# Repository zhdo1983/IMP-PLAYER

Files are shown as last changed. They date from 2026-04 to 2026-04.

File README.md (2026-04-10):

https://github.com/user-attachments/assets/7eb9eef1-41f4-46a2-858e-66c2568c89ac

mmexport1775849875180

IMP-PLAYER: The ESP32-WROOM Network Audio Terminal
1. Project Overview
IMP-PLAYER is a high-performance audio terminal based on the ESP32-WROOM-32 (No-PSRAM version). It is designed to push the hardware's physical limits, integrating network streaming, local playback, and complex UI interactions within a highly constrained memory environment.
mmexport1775849868553

🚀 Core Features
Network Streaming: High-stability streaming (MP3/AAC) with HTTPS support.

Navidrome Integration: Full Subsonic/Navidrome API support for personal cloud music.

SD Card Player: Local MP3 playback with dynamic folder scanning.

Advanced UI/UX: 128x64 OLED display with real-time spectrum analysis and smooth animations.

System Utilities: NTP network clock, battery monitoring, and a built-in PONG game.

Maintenance: Web-based WiFi configuration portal and OTA (Over-the-Air) firmware updates.

mmexport1775849851039

This project is specifically optimized for the Non-PSRAM ESP32-WROOM chip:

Dynamic Memory Orchestration: Implements a "模式切换即清场" (Clear-on-Switch) strategy. Metadata and buffers are dynamically allocated and freed to ensure 80KB+ contiguous heap for HTTPS handshakes.

Anti-Fragmentation Hack: Uses a "Silent Handshake" technique (connecting to 127.0.0.1) to force the network stack to flush buffers and defragment the heap before critical operations.

Multitasking: Decoupled FreeRTOS tasks for OLED rendering, audio decoding, and system monitoring.
2. Hardware
Component   Specification
MCU     	 ESP32-WROOM-32 (4MB Flash, No PSRAM)
Audio      DAC/Amp	MAX98357A I2S Class-D Amplifier
Display   	SSD1306 128x64 OLED (I2C)
Storage	   TF/MicroSD Card (SPI Mode)
Input	     EC11 Rotary Encoder
Lithium battery (3.7V) 602535P 600mAh x1
2.1 Pin Mapping
ESP32     Pin	     Component	Description
GPIO5	    SD_CS	SD    Card Chip Select
GPIO18   	SPI_SCK	    SD Card Clock
GPIO19	  SPI_MISO  	SD Card MISO
GPIO23	  SPI_MOSI	  SD Card MOSI
GPIO4   	OLED_SDA	  OLED I2C Data
GPIO14	  OLED_SCL	  OLED I2C Clock
GPIO25	  I2S_LRCK	  I2S Left/Right Clock
GPIO26	  I2S_BCLK	  I2S Bit Clock
GPIO22	  I2S_DOUT	  I2S Data Out
GPIO32	  ENC_A	      Encoder Phase A
GPIO33	  ENC_B	      Encoder Phase B
GPIO35	  ENC_SW	    Encoder Button
GPIO34	  BAT_ADC	    Battery Voltage Detection

3. Installation & Compilation
Prerequisites
Framework:  PlatformIO.

Required Libraries
Please install the following libraries via the Library Manager:

ESP32-audioI2S (by schreibfaul1)

U8g2 (by olikraus)

ArduinoJson

NTPClient

Configuration
Open config.h.

(Optional) Set your default WiFi credentials or use the Web Portal later.

Configure your Navidrome server address and API credentials.

### 🔨 Building with PlatformIO
This project uses **PlatformIO** for advanced memory and library management.

1. Clone the repository.
2. Open the folder in VS Code with the PlatformIO extension installed.
3. The `platformio.ini` will automatically handle dependencies (Audio, U8g2, ArduinoJson, etc.).
4. Click **Upload** to flash the ESP32-WROOM.

## 🔌 Hardware & PCB Design

The project includes complete hardware design files, allowing you to build your own IMP-PLAYER.

### Files Location:
### Files Location:
- **Schematic:** [/Hardware/PCB_PCB1_2026-04-11.pdf](./Hardware/PCB_PCB1_2026-04-11.pdf)  - Check here for pin definitions and circuit logic.
- **EasyEDA Project:** [/Hardware/ProDoc_PCB1_2026-04-11.EPRO2](./Hardware/ProDoc_PCB1_2026-04-11.EPRO2)
- You can import this directly into [LCEDA (EasyEDA)](https://pro.lceda.cn/) for modification.

### Key Hardware Features:
- **ESP32-WROOM-32** Core (Fully utilizing the internal SRAM).
- **MAX98357A** I2S DAC for high-quality audio output.
- **Battery Management:** Integrated charging circuit with ADC voltage monitoring.
- **Form Factor:** Optimized to fit the custom 3D-printed case.

### Manufacturing:
You can export the **Gerber files** from the `.EPRO2` file using EasyEDA and send them to manufacturers like JLCPCB for production.

3.1 Initial Configuration (Code Level)
Before flashing, you must set your default server endpoints in the source code:
----------------------------------------------------------------------------------------------------------
OTA Configuration: Locate lines 96-97 in config.h:
  #define OTA_DEFAULT_VER_URL  "http://your-server/version.txt"
  #define OTA_DEFAULT_FW_URL   "http://your-server/firmware.bin"
  Navidrome Default: Locate line 41 in navidrome.h:  
   #define ND_DEFAULT_SERVER "https://your-navidrome-url"

----------------------------------------------------------------------------------------------------------

5. Web Interface
The device hosts a local web server for advanced configuration:

Network: Scan and manage WiFi saved slots.

Navidrome: Configure server URL and User Token.

OTA: Upload new .bin firmware files wirelessly.

5.1 Backend Server Requirements
Navidrome Setup
Create a standard user account in your Navidrome instance.

You do not need to hardcode the password. Open the filebrowser Web Portal (after connecting to the device's WiFi) to enter the Username and Password. The device will automatically generate the MD5 Token for secure API communication.

OTA File Server
To use the OTA update feature, you need a simple HTTP file server (like Nginx, Apache, or a simple Python file server) hosting two files:

firmware.bin: The compiled binary of the project.

version.txt: A plain text file containing only the version number (e.g., 1.0.2).
The device compares the string in version.txt with its internal version to trigger an update.

6. Disclaimer & Contribution
⚠️ Disclaimer
This project is an experimental implementation of high-concurrency tasks on low-resource hardware. While it includes several memory-safety hacks (like the 127.0.0.1 handshake), unexpected reboots may occur under extreme network jitter or with overly large SD card directories (recommended < 500 tracks).

🤝 Contributing
This project was developed with the assistance of AI to optimize low-level memory management. If you find bugs or have ideas for even tighter memory optimization, please feel free to open an Issue or submit a Pull Request.

7. License
This project is licensed under the MIT License.

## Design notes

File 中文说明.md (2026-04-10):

# IMP-PLAYER
This is a player with functions including MP3 playback, network streaming media playback, Navidrome playback, music clock, and web service.
# ESP32-MAX98357 网络收音机使用说明书

## 一、项目概述

这是一个ESP32网络收音机和SD卡MP3播放器项目，采用模块化设计，主要特性包括：

**核心功能：**
- ✅ 网络电台流媒体播放（支持MP3/AAC格式）
- ✅ SD卡本地MP3文件播放
- ✅ 128x64 OLED显示屏（中文支持）
- ✅ 旋转编码器控制
- ✅ WiFi配置Portal
- ✅ OTA固件升级
- ✅ 电池电量监测
- ✅ PONG游戏
- ✅ NTP网络时钟同步

**硬件配置：**
- 主控：ESP32-WROOM-32
- 功放：MAX98357A I2S D类放大器
- 显示：SSD1306 128x64 OLED
- 存储：TF卡（SPI接口）
- 输入：EC11旋转编码器

## 二、硬件连接说明

### 2.1 引脚定义

| ESP32引脚 | 连接模块 | 说明 |
|---|---|---|
| GPIO5 | SD_CS | SD卡片选 |
| GPIO18 | SPI_SCK | SD卡时钟 |
| GPIO19 | SPI_MISO | SD卡数据输入 |
| GPIO23 | SPI_MOSI | SD卡数据输出 |
| GPIO4 | OLED_SDA | OLED I2C数据 |
| GPIO14 | OLED_SCL | OLED I2C时钟 |
| GPIO25 | I2S_DOUT | I2S音频输出 |
| GPIO26 | I2S_LRC | I2S左右声道时钟 |
| GPIO27 | I2S_BCLK | I2S位时钟 |
| GPIO21 | I2S_SD_MODE | MAX98357A使能 |
| GPIO32 | ENCODER_CLK | 编码器时钟 |
| GPIO16 | ENCODER_DT | 编码器数据 |
| GPIO17 | ENCODER_SW | 编码器按钮 |
| GPIO36 | BAT_DAC | 电池检测 |
| GPIO33 | LED_BLUE | 状态LED |

### 2.2 硬件清单

- ESP32-WROOM-32E *1
- MAX98357A I2S x2
- SSD1306 128x64 OLED显示屏 x1
- SD卡模块（SPI接口）x1
- TF卡 x1
- EC11旋转编码器 x1
- 锂电池（3.7V）602535P 600mah x1
- 充电管理模块 x1
- 扬声器（4Ω 3W）x2
- 若干电阻电容和杜邦线

-----------------------------------------------------------------------

OTA服务器和navidrome服务器录入方式：

 configh,h    96-97行 

#define OTA_DEFAULT_VER_URL  ""  // 默认版本检查URL
#define OTA_DEFAULT_FW_URL   ""  // 默认固件下载URL

navidrome.h 41行

ND_DEFAULT_SERVER "https://"  // 默认Navidrome服务器地址

---------------------------------------------------------------------------------------------------------------------
服务器端navidrome 建立用户， 在imp播放器WEB页面录入用户名密码
OTA服务器 使用impplayer文件服务器， 需要2个文件，一个firmware.bin， 一个version.txt
----------------------------------------------------------------------------------------------------------------------
喇叭使用 2030腔体喇叭

代码由于内存空间太小，使用中可能存在一些问题，若有发现，请分享给我
----------------------------------------------------------------------------------------------------------------------
项目中使用了很多其他网友的电路设计及代码设计， 在此感谢

=====================================================================================================================
## 三、首次使用指南

### 3.1 烧录固件

#### 使用PlatformIO编译和上传

### 3.2 WiFi配置

首次上电后设备会自动进入配网模式：

1. **连接WiFi热点**
   - 在手机或电脑WiFi列表中找到 `ESP32_Radio`
   - 连接该热点（无密码）

2. **打开配置页面**
   - 在浏览器中访问：`http://192.168.3.3`
   - 会看到配置界面

3. **输入WiFi信息**
   - 输入你的WiFi名称（SSID）
   - 输入WiFi密码
   - 点击"添加WiFi"按钮
   - 可以添加最多5个WiFi账号

4. **保存并重启**
   - 点击底部的"保存并重启"按钮
   - 设备会自动重启并连接WiFi

### 3.3 测试播放

重启后设备会自动：
- 连接WiFi
- 播放默认电台（默认为第8个电台：Radio Paradise）

**基本操作：**
- 旋转编码器：调节音量（0-21级）
- 按下编码器按钮：进入主菜单

## 四、功能使用说明

### 4.1 主菜单操作

按下编码器按钮进入主菜单，包含以下功能：

1. **选择电台** - 选择网络电台播放
2. **SD卡播放器** - 播放SD卡MP3文件
3. **时钟显示** - 显示NTP网络时间
4. **PONG游戏** - 弹球游戏
5. **WiFi设置** - 重新配置WiFi
6. **恢复出厂设置** - 恢复默认电台列表
7. **内存分配** - 查看内存使用情况

**菜单操作：**
- 旋转编码器：上下移动选择项
- 按下按钮：确认选择
- 10秒无操作自动返回

### 4.2 网络电台播放

**选择电台：**
1. 在主菜单选择"1.选择电台"
2. 旋转选择电台
3. 按下确认播放

**电台管理：**
- 通过Web界面管理电台
- 访问设备IP地址
- 可以添加、编辑、删除电台
- 最多保存20个电台

**默认电台列表：**
1. 德意志广播电台 WDR Einslive
2. 经典欧美 181.FM - Awesome 80's
3. 法国广播电台
4. 俄罗斯 PADNO
5. 德国 Hit-Radio FFH
6. 马来西亚 RTM Radio
7. 新加坡 88.3jia
8. 天堂电台 Radio Paradise
9. 芝加哥 WZRD The Wizard 88.3 FM
10. 苏腊巴亚 smart FM88.9
11. AFN Daegu - Korea
12. Swiss Jazz (瑞士爵士乐)

### 4.3 SD卡播放器

**准备工作：**
1. 将TF卡格式化为FAT32
2. 将MP3文件复制到卡中（支持子目录）
3. 将TF卡插入SD卡模块

**使用SD卡播放器：**
1. 在主菜单选择"2.SD卡播放器"
2. 首次使用会自动扫描SD卡
3. 扫描完成后自动开始播放

**播放控制：**
- 进入SD播放器控制菜单
- 旋转选择控制选项
  1. 下一首
  2. 上一首
  3. 播放/暂停
  4. 播放模式
  5. PONG游戏
  6. 切换效果图
  7. 退出

**播放模式：**
1. 单曲循环 - 当前曲目循环播放
2. 顺序播放 - 按列表顺序播放
3. 随机播放 - 随机选择曲目

**播放动画：**
- 12种播放动画可选
- 在"切换效果图"菜单中设置
- 动画效果包括：九宫格、圆环、五分割圆环、三角形切换、旋转圆弧、音频指示器、正弦频谱、爱心跳动、方块滚动、日月旋转、斜线下雨、气泡上升

**退出SD播放：**
- 选择"7.退出"选项
- 设备会自动释放资源并重启

### 4.4 时钟显示

1. 在主菜单选择"3.时钟显示"
2. 设备会自动从NTP服务器同步时间
3. 显示当前网络时间
4. 按下按钮返回主菜单

### 4.5 PONG游戏

1. 在主菜单选择"4.PONG游戏"
2. 游戏规则：
   - 控制左侧挡板
   - 击球到对方得一分
   - 先得5分获胜
3. 操作：
   - 旋转编码器控制挡板上下移动
   - 按下按钮返回主菜单

### 4.6 WiFi设置

**重新配置WiFi：**
1. 在主菜单选择"5.WiFi设置"
2. 设备会进入配网模式
3. 按照首次使用配置WiFi的步骤操作

**WiFi多账号管理：**
- 最多保存5个WiFi账号
- 设备启动时自动选择信号最强的连接
- 可以通过Web界面添加或删除WiFi

### 4.7 恢复出厂设置

1. 在主菜单选择"6.恢复出厂设置"
2. 设备会恢复默认电台列表
3. 恢复默认设置
4. 自动重启

### 4.8 内存分配查看

1. 在主菜单选择"7.内存分配"
2. 显示当前内存使用情况
3. 信息包括：
   - 总内存
   - 空闲内存
   - WiFi占用
   - SSL占用
   - 音频占用

### 4.9 OTA固件升级

**检查更新：**
1. 在主菜单→播放器选择→选择"OTA"选项
2. 设备会自动检查服务器版本
3. 如果有新版本，会提示升级

**执行升级：**
1. 选择"1.升级"开始升级
2. 升级过程中不要断电
3. 升级完成后自动重启

## 五、串口命令

通过串口终端可以输入以下命令：

### 5.1 可用命令

```
help          - 显示帮助信息
refresh       - 刷新SD卡数据库
refreshsd     - 刷新SD卡数据库（同上）
dbinfo        - 显示数据库信息
<URL>         - 直接播放网络流（输入URL）

## 六、Web管理界面

### 6.1 访问Web界面

1. 确保设备已连接WiFi
2. 在串口输出中查看设备IP地址
3. 在浏览器中访问该IP地址

### 6.2 电台管理

**查看电台列表：**
- 页面显示所有已保存的电台
- 显示电台名称和URL

**添加电台：**
1. 在"添加新电台"区域输入电台名称
2. 输入电台URL
3. 点击"添加电台"按钮

**编辑电台：**
1. 直接在列表中修改电台名称和URL
2. 点击"保存"按钮

**删除电台：**
1. 点击电台右侧的"删除"按钮
2. 确认删除

### 6.3 WiFi管理

**查看WiFi列表：**
- 显示所有已保存的WiFi账号
- 显示SSID（不显示密码）

**添加WiFi：**
1. 在"新增 WiFi 名称"输入SSID
2. 在"密码"输入WiFi密码（无密码留空）
3. 点击"添加 WiFi"按钮

**删除WiFi：**
1. 点击WiFi右侧的"删除"按钮
2. 确认删除

## 七、常见问题解答

### 7.1 连接问题

**Q: WiFi连接失败？**
A:
- 检查WiFi密码是否正确
- 尝试重启设备
- 检查WiFi信号强度
- 尝试删除后重新添加WiFi账号

**Q: SD卡无法识别？**
A:
- 确保SD卡格式化为FAT32
- 使用Class 10或更高速的SD卡
- 检查SD卡是否损坏
- 重新插拔SD卡

**Q: 播放无声音？**
A:
- 检查I2S接线是否正确
- 确保MAX98357A供电正常（3.3V-5V）
- 检查扬声器连接
- 确认音量已调节

### 7.2 播放问题

**Q: 电台播放卡顿？**
A:
- 检查网络连接质量
- 尝试更换其他电台
- 检查WiFi信号强度
- 重启设备

**Q: SD播放失败？**
A:
- 确认MP3文件格式正确
- 检查文件是否损坏
- 确认SD卡容量未满
- 重新扫描SD卡

**Q: 频繁自动重启？**
A:
- 可能是内存不足
- 减少SD卡MP3数量
- 优化播放列表
- 检查是否超过最大曲目数（500首）

### 7.3 内存问题

**Q: 如何查看内存使用？**
A:
- 进入主菜单→内存分配
- 查看详细的内存信息
- 监控内存变化

**Q: 内存不足怎么办？**
A:
- 减少SD卡MP3数量
- 优化电台列表
- 避免频繁切换电台
- 重启设备释放内存

### 7.4 其他问题

**Q: 电池电量显示不准？**
A:
- 电池检测基于ADC值，需要校准
- 根据实际电池特性调整参数
- 查看电池.h文件中的ADC阈值

**Q: 如何更新固件？**
A:
- 通过OTA升级（见4.9节）
- 或通过USB重新烧录固件

**Q: 串口波特率是多少？**
A: 115200

## 八、技术规格

### 8.1 硬件参数

| 参数 | 数值 |
|------|------|
| 工作电压 | 3.3V / 5V (USB供电) |
| 锂电池电压 | 3.7V |
| 音频输出 | 3W @ 4Ω |
| 显示屏 | 128x64 OLED |
| 存储卡支持 | 最大32GB FAT32 |
| 音频格式 | MP3, AAC, FLAC, WAV |
| 串口波特率 | 115200 |
| WiFi频段 | 2.4GHz |

## 九、开发说明

### 9.1 项目结构src/
├── main.cpp             # 主程序入口、全局变量定义
├── config.h             # 硬件配置和常量定义
├── globals.h            # 全局变量声明
├── display.h            # OLED显示驱动、菜单、滚动
├── oled_task.h          # OLED显示任务
├── wifi_config.h        # WiFi连接、配网portal、Web服务器
├── stations.h           # 网络电台管理、预设电台列表
├── sd_player.h          # SD卡MP3播放、文件扫描
├── encoder.h            # 旋转编码器驱动、按钮事件
├── audio_manager.h      # 音频管理、内存清理
├── menu.h               # 菜单处理、状态管理
├── battery.h            # 电池检测
├── ota.h                # OTA升级功能
├── boot_animation.h     # 开机动画
├── icons.h              # 图标定义
└── 使用说明书.md          # 本文件

## 十一、许可协议

MIT License

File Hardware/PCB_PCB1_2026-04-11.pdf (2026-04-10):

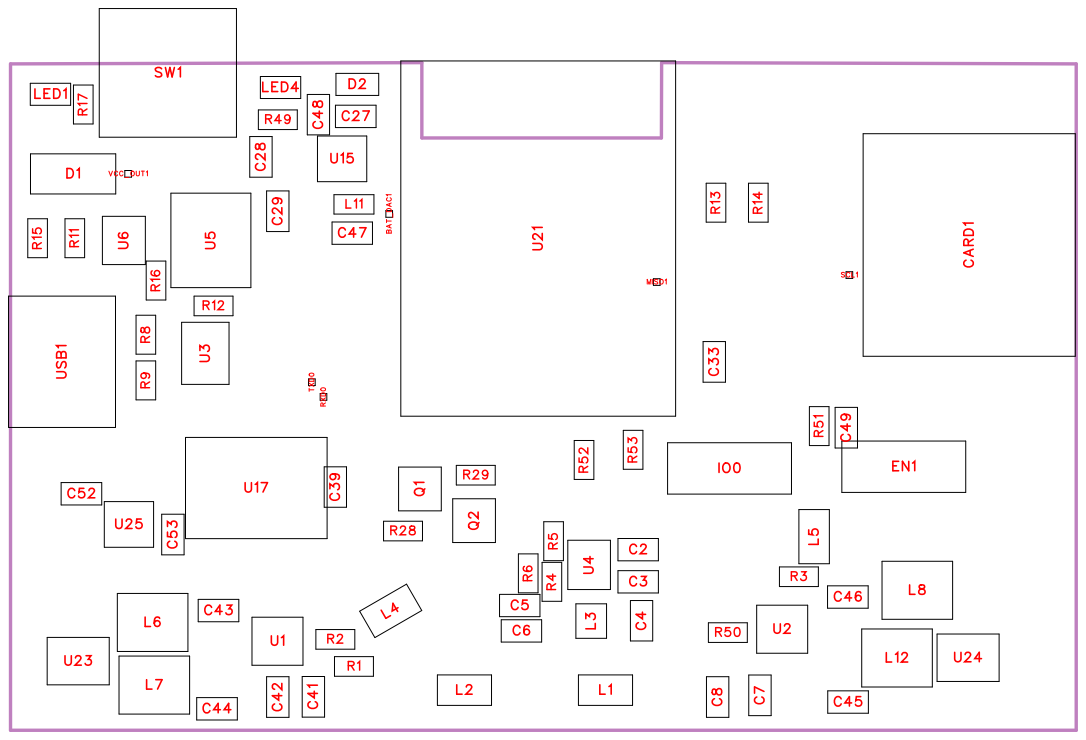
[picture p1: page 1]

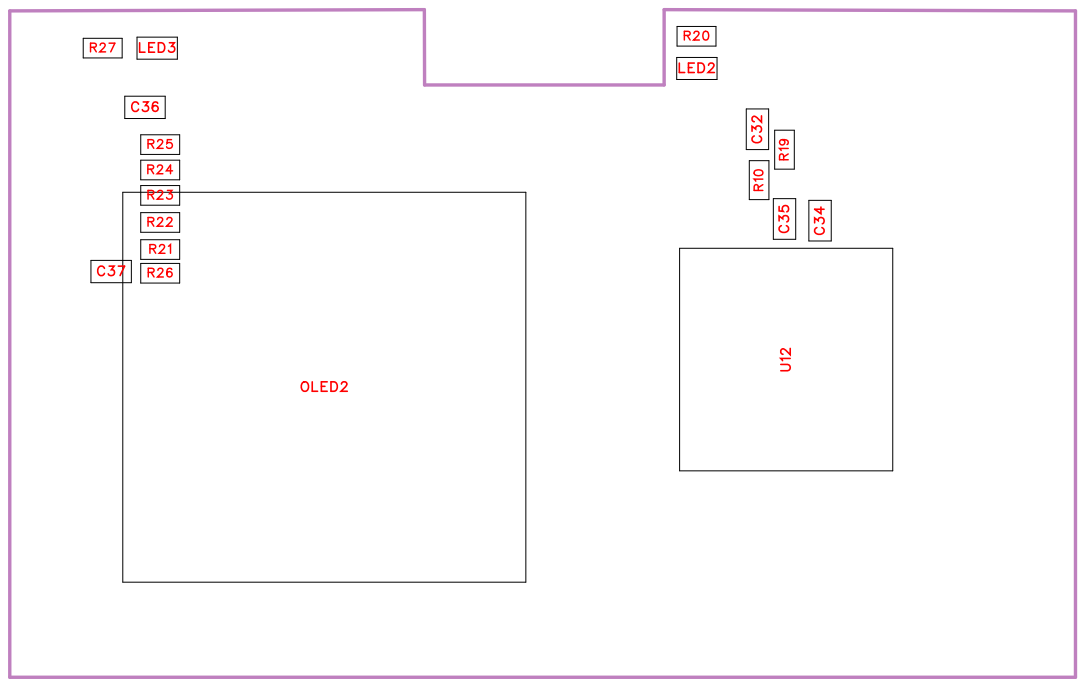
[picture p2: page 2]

No. | Category | Quantity | Designator | Footprint | Value | Manufacturer Part | JLCPCB Price | Comment | LCSC Price | Device | Name
1 | | 6 | BAT_DAC1,MISO1,RXD0,S CL1,TXD0,VCC_OUT1 | Test-Point-0. 5mm | | | | Test-Point | | Test-Point
2 | | 2 | C2,C5 | C0603_4 | 100nF | CL10B104K O8NNNC | 0.0265 | 100nF | 0.0265 | CL10B104K O8NNNC | 100nF
3 | | 2 | C3,C6 | C0603_4 | 10uF | CL10A106M Q8NNNC | 0.038 | 10uF | 0.038 | CL10A106M Q8NNNC | 10uF
4 | | 1 | C4 | C0603_4 | 22pF | CL10C220JB 8NNNC | 0.0238 | 22pF | 0.0238 | CL10C220JB 8NNNC | 22pF
5 | Capacitors:M ultilayer Ceramic Capacitors MLCC -SMD/SMT | 2 | C7,C41 | C0603_5 | 1uF | 0603F105M1 60NT | 0.0326 | 1uF | 0.0326 | 0603F105M1 60NT
6 | Capacitors:M ultilayer Ceramic Capacitors MLCC -SMD/SMT | 2 | C8,C42 | C0603_5 | 10uF | GRM188R6Y A106MA73J | 0.705 | 10uF | 0.7047 | GRM188R6Y A106MA73J
7 | Capacitors:M ultilayer Ceramic Capacitors MLCC -SMD/SMT | 3 | C27,C29,C52 | C0603 | 10uF | CL10A106M A8NRNC | 0.113 | 10uF | 0.1128 | CL10A106M A8NRNC | 10uF
8 | Capacitors:M ultilayer Ceramic Capacitors MLCC -SMD/SMT | 2 | C28,C53 | c0603_1 | 10uF | CL10A106M A8NRNC | 0.113 | 10uF | 0.1128 | CL10A106M A8NRNC | 10uF
9 | Capacitors:M ultilayer Ceramic Capacitors MLCC -SMD/SMT | 1 | C32 | C0603 | 10nF | CL10B103KB 8NNNC | 0.022 | 10nF | 0.022 | CL10B103KB 8NNNC | 10nF
10 | Capacitors:M ultilayer Ceramic Capacitors MLCC -SMD/SMT | 3 | C33,C34,C35 | c0603_1 | 100nF | CL10B104KB 8NNNC | 0.0175 | 100nF | 0.0175 | CL10B104KB 8NNNC | 100nF
11 | | 3 | C36,C47,C48 | C0603_4 | 100nF | | | 100nF | | CAP_0603 | 100nF
12 | | 1 | C37 | C0603_4 | 10UF | | | 10UF | | CAP_0603 | 10UF
13 | | 1 | C39 | C0603_4 | 100nF/50v | | | 100nF/50v | | CAP_0603 | 100nF/50v

14 | Capacitors:M ultilayer Ceramic Capacitors MLCC -SMD/SMT | 4 | C43,C44,C45,C46 | C0603_5 | 220nF | CL10B224KA 8NNNC | 0.0468 | 220nF | 0.0468 | CL10B224KA 8NNNC
15 | | 1 | C49 | C0603_3 | | | | 10uF | | 10uF | 10uF
16 | 连接器:SD / 卡 存储卡连接器 | 1 | CARD1 | TF-SMD_TF-PUSH | | TF PUSH | 0.401 | TF PUSH | 0.4041 | TF PUSH | TF PUSH
17 | 二极管 :肖特 基二极管 | 1 | D1 | SMA_L4.3-W 2.6-LS5.2-R D | | SS34 | 0.186 | SS34 | 0.1857 | SS34_C8678 | SS34
18 | TVS/保险丝 / : 板级保护 静 电放电(ESD) 保护器件 | 1 | D2 | SOD-323_L1 .7-W1.3-LS2. 5-BI | | TPPESD3V3 L1BA | 0.283 | TPPESD3V3 L1BA | 0.2829 | TPPESD3V3 L1BA | TPPESD3V3 L1BA
19 | Key/Switch:T actile Switches | 2 | EN1,IO0 | KEY-SMD_L 6.0-W3.6-LS 8.3-L | | TC-3602-4.3-260G | 0.369 | TC-3602-4.3-260G | 0.3688 | TC-3602-4.3-260G | TC-3602-4.3-260G
20 | 磁珠 /滤波器 / EMI优化 :磁珠 | 2 | L1,L2 | L0805 | | CBW201209 U301T | 0.109 | CBW201209 U301T | 0.1092 | CBW201209 U301T | CBW201209 U301T
21 | 电感 /线圈 / 变 压器 :功率电 感 | 1 | L3 | IND-SMD_L2 .5-W2.0-VLS 252012CX-1 50M | 2.2uH | FXLB252012 -2R2-M | 0.472 | 2.2uH | 0.4742 | FXLB252012 -2R2-M | 2.2uH
22 | 磁珠 /滤波器 / EMI优化 :磁珠 | 2 | L4,L5 | L0805 | | CBM201209 U301T | 0.105 | 磁珠 | 0.1045 | CBM201209 U301T | 磁珠
23 | 电感 /线圈 / 变 压器 :功率电 感 | 4 | L6,L7,L8,L12 | IND-SMD_L4 .6-W4.1-A | 22uH | SRG0420-22 0-M | 0.881 | 22uH | 0.8807 | SRG0420-22 0-M | 22uH
24 | | 1 | L11 | L0603 | 2nh | | | 2nh | | L_0603 | 2nh
25 | Optoelectroni cs:LED Indication -Discrete | 1 | LED1 | LED0603-RD _RED_2 | | NCD0603R1 | 0.0622 | NCD0603R1 | 0.0622 | NCD0603R1 _C84263_1 | NCD0603R1
26 | 光电器件 : 发 光二极管 | 2 | LED2,LED3 | LED_0603 | | | | LED_0603-R | | LED_0603-R
27 | 光耦/LED/ 数 /光电器 码管 :发光二极 件 管/LED | 1 | LED4 | led0603-rd_r ed_1 | | NCD0603R1 | 0.0622 | NCD0603R1 | 0.0622 | NCD0603R1 _C84263 | NCD0603R1
28 | | 1 | OLED2 | 0.96OLED_4 P | | 0.96OLED_4 P_MODULE_ JX | 0.004 | 0.96OLED_4 P_MODULE_ JX | | 0.96OLED_4 P_MODULE_ JX | 0.96OLED_4 P_MODULE_ JX
29 | 三极管/MOS 管/晶体管:三 极管(BJT) | 2 | Q1,Q2 | SOT-23-3_L2 .9-W1.3-P1.9 0-LS2.4-BR | | SS8050 | 0.0662 | SS8050 | 0.0669 | SS8050_C74 20370 | SS8050
30 | 电阻 :贴片电 阻 | 2 | R1,R3 | R0603_4 | 100K | | | 100K | | Res_0603 | 100K

31 | Resistors:Chi p Resistor -Surface Mount | 1 | R2 | R0603_1 | 2k | 0603WAF20 01T5E | 0.0085 | 2k | 0.0085 | 0603WAF20 01T5E
32 | | 1 | R4 | R0603_4 | 680k | 0603WAF68 03T5E | 0.0093 | 680k | 0.0093 | 0603WAF68 03T5E | 680k
33 | | 1 | R5 | R0603_4 | 150k | 0603WAF15 03T5E | 0.0078 | 150k | 0.0078 | 0603WAF15 03T5E | 150k
34 | | 1 | R6 | R0603_4 | 10k | 0603WAF10 02T5E | 0.0079 | 10k | 0.0079 | 0603WAF10 02T5E | 10k
35 | Resistors:Chi p Resistor -Surface Mount | 2 | R8,R9 | R0603_5 | 5.1k | RC0603FR-0 75K1L | 0.0094 | 5.1k | 0.0094 | RC0603FR-0 75K1L | 5.1k
36 | 电阻 :贴片电 阻 | 2 | R10,R19 | R0603_5 | 100k | RC0603FR-0 7100KL | 0.0084 | 100k | 0.0084 | RC0603FR-0 7100KL | 100k
37 | Resistors:Chi p Resistor -Surface Mount | 2 | R11,R17 | R0603_5 | 1k | RC0603FR-0 71KL | 0.0088 | 1k | 0.0088 | RC0603FR-0 71KL | 1k
38 | Resistors:Chi p Resistor -Surface Mount | 1 | R12 | R0603_5 | 1.2k | RC0603FR-0 72K2L | | 1.2k | | RC0603FR-0 72K2L | 1.2k
39 | Resistors:Chi p Resistor -Surface Mount | 3 | R13,R14,R15 | R0603_5 | 10k | RC0603FR-0 710KL | 0.0089 | 10k | 0.0089 | RC0603FR-0 710KL | 10k
40 | Resistors:Chi p Resistor -Surface Mount | 1 | R16 | R0603_5 | 500m | RL0603FR-0 70R5L | 0.118 | 500m | 0.1175 | RL0603FR-0 70R5L | 500m
41 | 电阻 :贴片电 阻 | 10 | R20,R21,R22,R23,R24,R25 ,R26,R27,R28,R29 | R0603_4 | 10K | | | 10K | | Res_0603 | 10K
42 | 电阻 :贴片电 阻 | 1 | R49 | r0603_3 | 2.2k | RS-03K222J T | 0.0076 | 2.2k | 0.0076 | RS-03K222J T | 2.2k
43 | Resistors:Chi p Resistor -Surface Mount | 1 | R50 | R0603_1 | 226k | 0603WAF22 63T5E | 0.0078 | 226k | 0.0078 | 0603WAF22 63T5E
44 | | 3 | R51,R52,R53 | R0603 | | | | 10k | | 10k | 10k
45 | 按键 /开关 : 滑 动开关 | 1 | SW1 | SW-TH_SK1 2D07VG5-1 | | SK12D07VG 5 | 0.14 | SK12D07VG 5 | 0.1413 | SK12D07VG 5 | SK12D07VG 5
46 | 运算放大器 / :音频 比较器 功率放大器 | 2 | U1,U2 | TQFN-16_L3 .0-W3.0-P0.5 0-BL-EP1.5 | | MAX98357A ETE+T | 8.8 | MAX98357A ETE+T | 8.8 | MAX98357A ETE+T | MAX98357A ETE+T
47 | 连接器 :线对 板针座 | 3 | U3,U23,U24 | CONN-TH_2 P-P1.25_ME GASTAR_ZX -MX1.25-2PZ Z | | ZX-MX1.25-2 PZZ | 0.0883 | ZX-MX1.25-2 PZZ | 0.0892 | ZX-MX1.25-2 PZZ | ZX-MX1.25-2 PZZ

48 | 电源管理:DC-DC电源芯片 | 1 | U4 | SOT-23-5_L3 .0-W1.7-P0.9 5-LS2.8-BR_ 1 | SY8088AAC | 0.573 | SY8088AAC | 0.5728 | SY8088AAC | SY8088AAC
49 | 电源芯片 : 电 池管理 | 1 | U5 | ESOP-8_L4. 9-W3.9-P1.2 7-LS6.0-BL-E P | TP4056 | 0.403 | TP4056 | 0.4073 | TP4056_C72 5790 | TP4056
50 | | 1 | U6 | SOT-23-3_L2 .9-W1.6-P1.9 0-LS2.8-BR | AO3401 | 0.004 | AO3401 | | AO3401 | AO3401
51 | | 1 | U12 | SW-SMD_E C1106S | EC1106S | 0.004 | EC1106S | | EC1106S | EC1106S
52 | 电源管理 : 线 性稳压器(LD O) | 2 | U15,U25 | SOT-23-5_L3 .0-W1.7-P0.9 5-LS2.8-BR | ME6217C33 M5G | 0.485 | ME6217C33 M5G | 0.4848 | ME6217C33 M5G | ME6217C33 M5G
53 | 通信接口芯片 :USB转换芯 片 | 1 | U17 | SOP-16_L10. 0-W3.9-P1.2 7-LS6.0-BL | CH340C | 3.6 | CH340C | 3.6 | CH340C | CH340C
54 | 物联网 /通信 模块:WiFi 模 块 | 1 | U21 | WIFI-SMD_E SP32-WROO M-32E | ESP32-WRO OM-32E-N4 | 23.46 | ESP32-WRO OM-32E-N4 | 23.46 | ESP32-WRO OM-32E-N4 | ESP32-WRO OM-32E-N4
55 | Connectors: USB Connectors | 1 | USB1 | USB-C-SMD _TYPE-C-6PI N-2MD-073 | TYPE-C 16PIN 2MD(073) | 0.409 | TYPE-C 16PIN 2MD(073) | 0.4127 | TYPE-C 16PIN 2MD(073) | TYPE-C 16PIN 2MD(073)

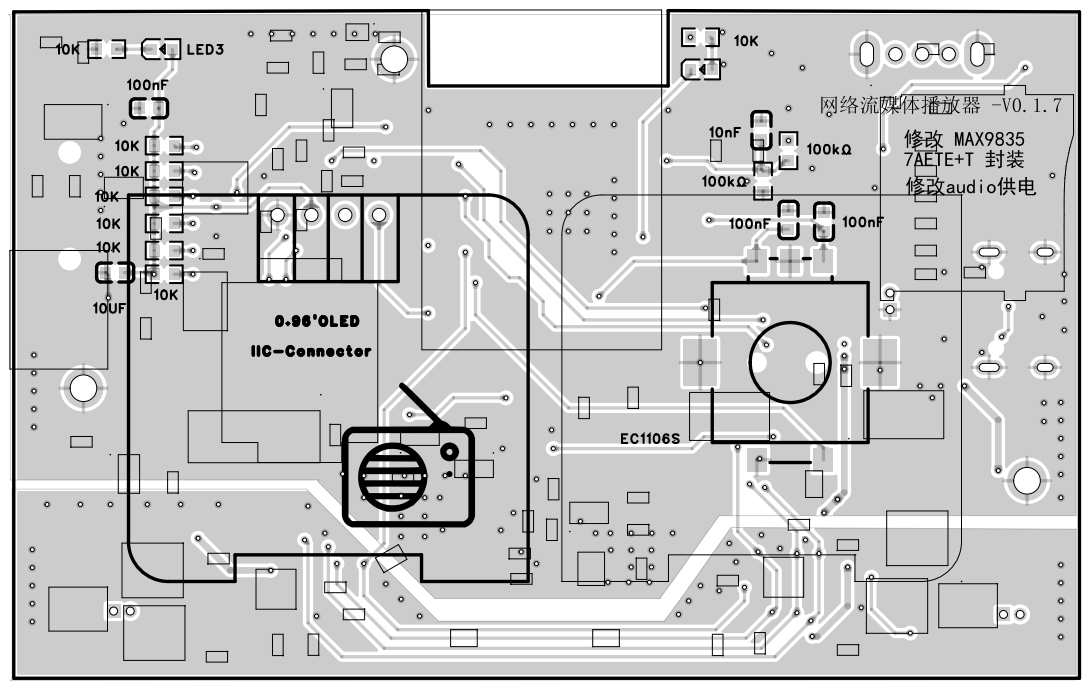
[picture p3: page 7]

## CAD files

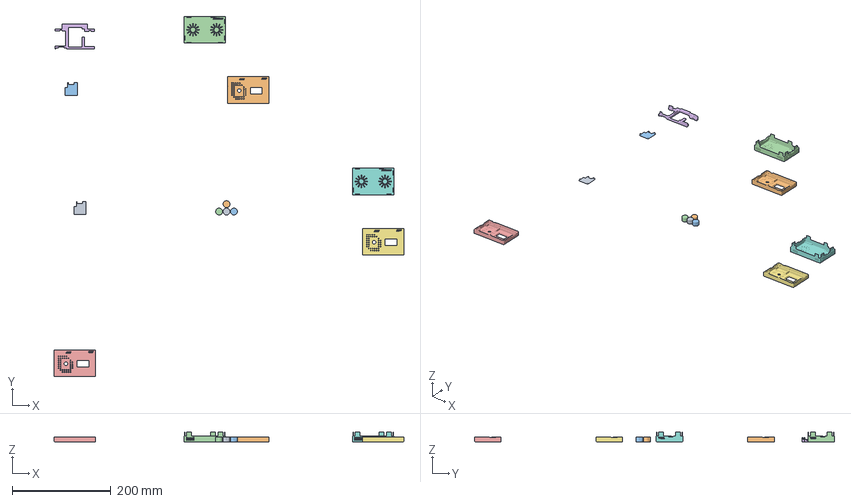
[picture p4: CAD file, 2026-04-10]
3D model/外壳.3mf
708.4 x 729.4 x 19.5 mm
12864底座.STEP x 2
前壳.STEP x 3
后盖.STEP x 2
中板.STEP
按钮.STEP x 4

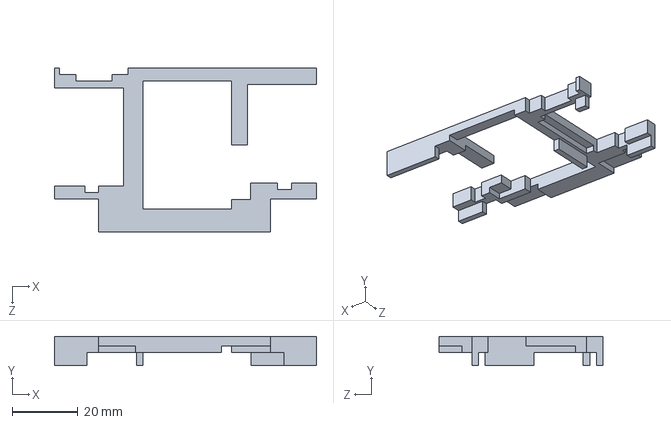
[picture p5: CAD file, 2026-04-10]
3D model/中板.STEP
80.0 x 9.00 x 50.0 mm

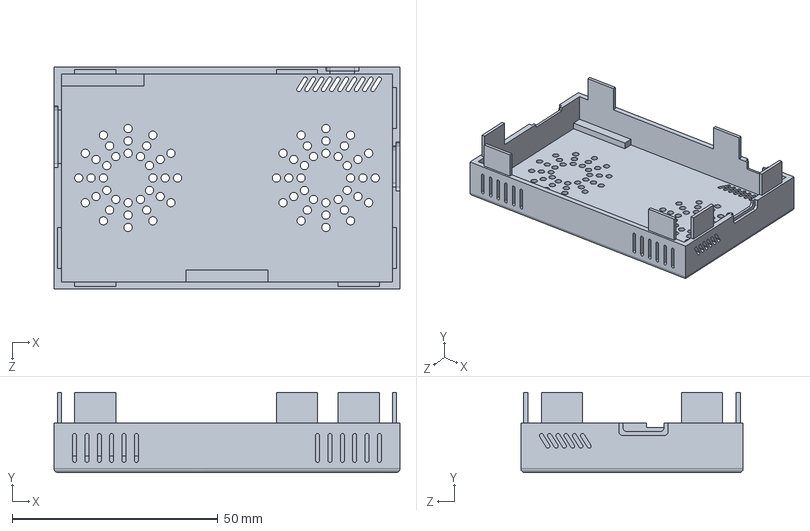
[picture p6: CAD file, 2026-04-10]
3D model/后盖.STEP
84.0 x 19.5 x 54.0 mm

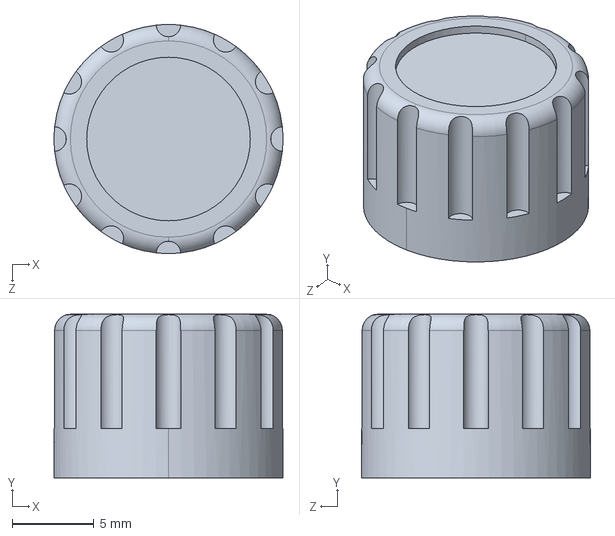
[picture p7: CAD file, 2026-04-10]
3D model/按钮.STEP
14.0 x 10.0 x 14.0 mm

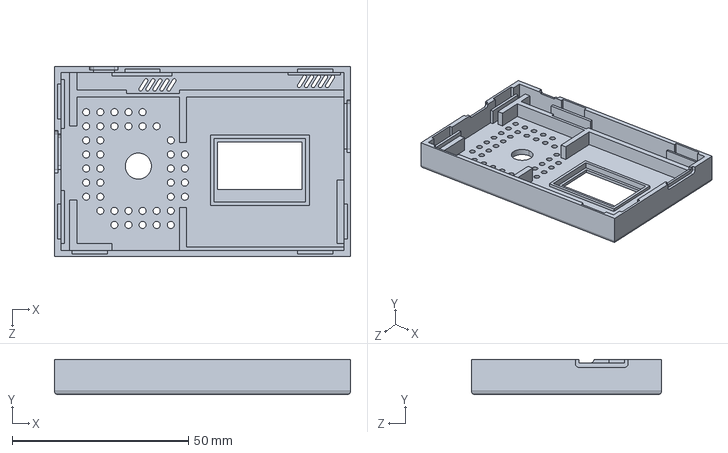
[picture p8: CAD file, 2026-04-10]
3D model/前壳.STEP
84.0 x 10.0 x 54.0 mm

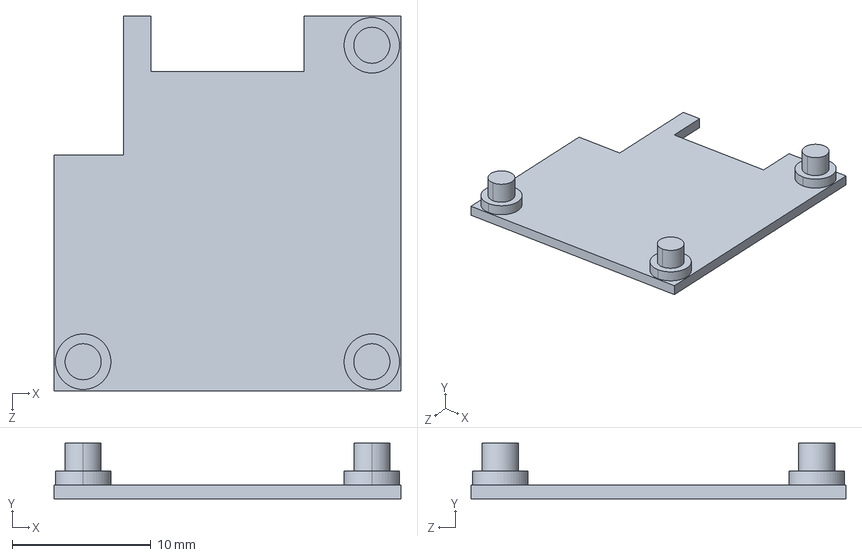
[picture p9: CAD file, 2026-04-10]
3D model/12864底座.STEP
25.0 x 4.00 x 27.0 mm

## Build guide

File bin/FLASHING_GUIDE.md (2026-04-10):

\# IMP-PLAYER 烧录指南 | Flashing Guide

\## 中文说明

\### 一、所需工具与文件

1\. 烧录工具：flash\_download\_tool（乐鑫官方）

2\. 3 个固件文件

&#x20;  - bootloader.bin

&#x20;  - partitions.bin

&#x20;  - firmware.bin

3\. 硬件：ESP32-WROOM-32（4MB Flash，无PSRAM）、USB 数据线

4\. 电脑系统：Windows

\---

\### 二、工具下载（官方安全）

https://www.espressif.com/zh-CN/support/download/other-tools

下载后解压到任意文件夹，直接运行 `flash\_download\_tool.exe`，无需安装。

\---

\### 三、烧录步骤（零基础可操作）

1\. 打开工具，芯片选择 \*\*ESP32\*\*，点击 OK

2\. 按以下配置添加文件并勾选：

&#x20;  - bootloader.bin    地址：0x1000

&#x20;  - partitions.bin    地址：0x8000

&#x20;  - firmware.bin      地址：0x10000

3\. 底部参数设置

&#x20;  - SPI Speed：40MHz

&#x20;  - SPI Mode：DIO

&#x20;  - Flash Size：4MB

4\. 选择正确的 COM 端口

5\. 点击 \*\*START\*\* 开始烧录

6\. 显示 \*\*FINISH\*\* 即为烧录成功

\---

\### 四、常见问题

1\. 烧录失败：按住开发板 \*\*BOOT\*\* 键再点击 START，进度条走动后松开

2\. 找不到 COM 口：安装 CH340/CP2102 驱动，更换 USB 线

3\. 烧录后不运行：检查地址是否正确、Flash Size 是否设为 4MB

\---

\---

\## English Instruction

\### 1. Required Tools \& Files

1\. Flashing Tool: flash\_download\_tool (Espressif Official)

2\. 3 Firmware Files

&#x20;  - bootloader.bin

&#x20;  - partitions.bin

&#x20;  - firmware.bin

3\. Hardware: ESP32-WROOM-32 (4MB Flash, No PSRAM), USB Cable

4\. OS: Windows

\---

\### 2. Tool Download (Official \& Safe)

https://www.espressif.com/en/support/download/other-tools

Extract the ZIP package, run `flash\_download\_tool.exe` directly. No installation required.

\---

\### 3. Flashing Steps (For Beginners)

1\. Open the tool, select \*\*ESP32\*\*, click OK

2\. Add and check files as below:

&#x20;  - bootloader.bin    Address: 0x1000

&#x20;  - partitions.bin    Address: 0x8000

&#x20;  - firmware.bin      Address: 0x10000

3\. Bottom Settings

&#x20;  - SPI Speed: 40MHz

&#x20;  - SPI Mode: DIO

&#x20;  - Flash Size: 4MB

4\. Select the correct COM port

5\. Click \*\*START\*\* to flash

6\. \*\*FINISH\*\* means flashing completed

\---

\### 4. Troubleshooting

1\. Flash failed: Hold the \*\*BOOT\*\* button, click START, release after progress starts

2\. No COM port: Install CH340/CP2102 driver, change USB cable

3\. Not running after flash: Check addresses and set Flash Size to 4MB

\---

\### 固定烧录参数 | Fixed Configuration

\- bootloader.bin  : 0x1000

\- partitions.bin  : 0x8000

\- firmware.bin    : 0x10000

\- SPI Mode        : DIO

\- Flash Size      : 4MB

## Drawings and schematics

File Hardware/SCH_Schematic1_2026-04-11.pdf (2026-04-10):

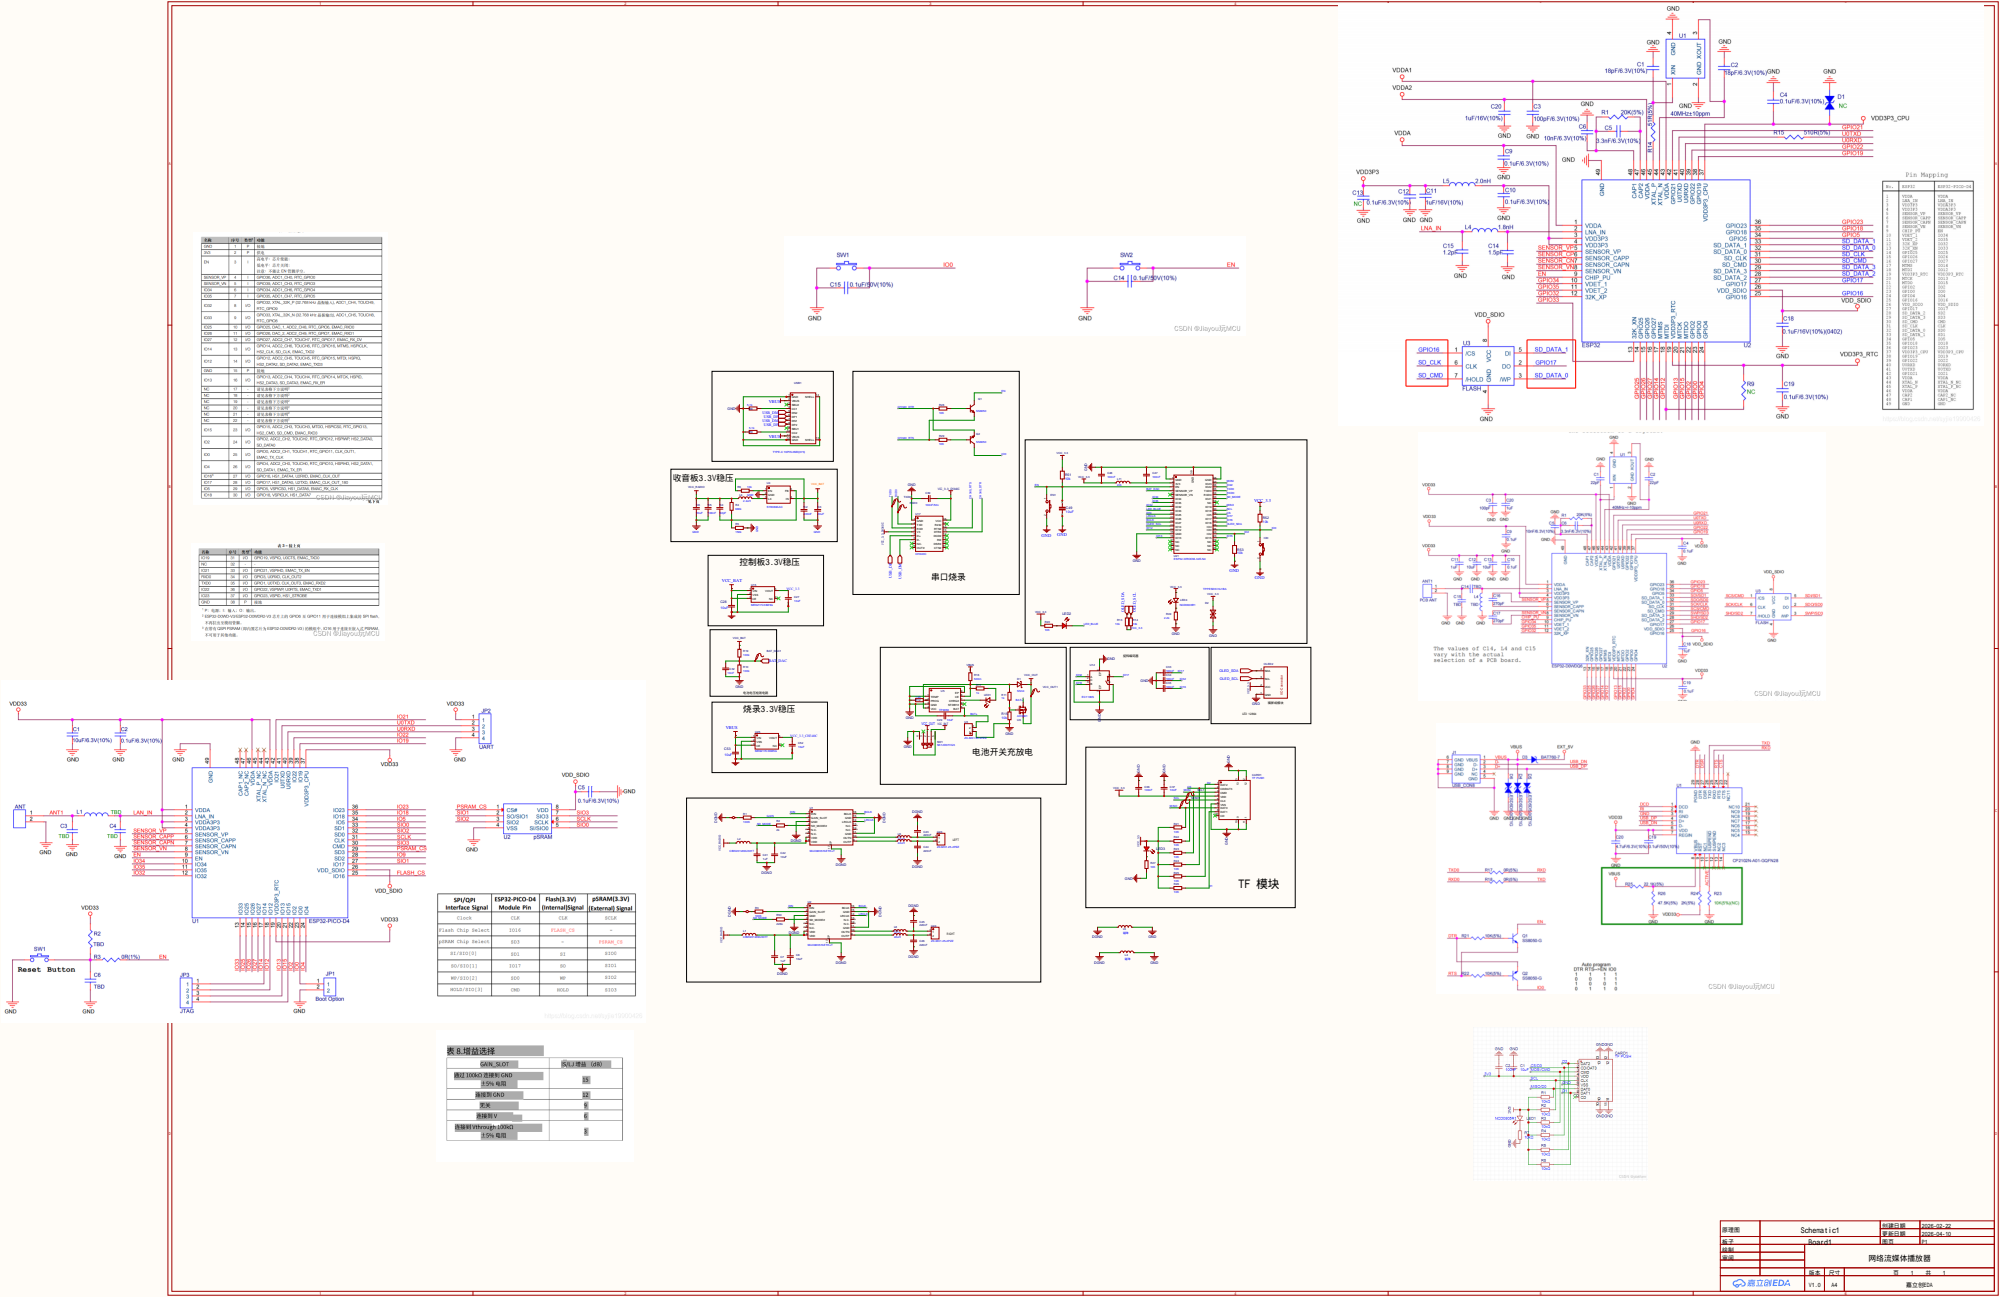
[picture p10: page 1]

原理图 | Schematic1 | 创建日期 | 2026-02-22

更新日期 | 2026-04-10

板子 | Board1 | 图页 | P1
绘制 | | 网络流媒体播放器
审阅

V1.0 | A4 | 嘉立创EDA

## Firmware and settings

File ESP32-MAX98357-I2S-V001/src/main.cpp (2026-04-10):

//**********************************************************************************************************
// ESP32 网络收音机 + SD 卡播放器
// 重构版本：按功能拆分为多个头文件
//**********************************************************************************************************

#include "Arduino.h"  // Arduino核心库
#include "WiFiMulti.h"  // WiFi多连接库
#include "Audio.h"  // 音频播放库
#include "SPI.h"  // SPI通信库
#include "SD.h"  // SD卡库
#include "FS.h"  // 文件系统库
#include <U8g2lib.h>  // OLED显示库
#include <Wire.h>  // I2C通信库
#include <WebServer.h>  // Web服务器库
#include <DNSServer.h>  // DNS服务器库
#include <Preferences.h>  // 非易失性存储库
#include <time.h>  // 时间库
#include <HTTPClient.h>  // HTTP客户端库
#include <Update.h>  // OTA更新库
#include <freertos/task.h>  // FreeRTOS任务库
#include <freertos/semphr.h>  // FreeRTOS信号量库
#include <esp_task_wdt.h>  // 看门狗库
#include <NTPClient.h>  // NTP时间同步库

// 功能模块头文件
#include "config.h"  // 系统配置参数
#include "globals.h"  // 全局变量声明
#include "boot_animation.h"  // 开机动画
#include "icons.h"  // 图标定义
#include "battery.h"  // 电池检测
#include "ota.h"  // OTA升级功能
#include "stations.h"  // 电台管理
#include "audio_manager.h"  // 音频管理
#include "sd_player.h"  // SD卡播放器
#include "encoder.h"  // 编码器控制
#include "wifi_config.h"  // WiFi配置
#include "display.h"  // 显示相关
#include "menu.h"  // 菜单处理
#include "navidrome.h"  // Navidrome网络音乐播放器
#include "alarm_clock.h"  // 音乐闹钟

//===========================================================================
// 全局对象定义（globals.h 中声明为 extern）
//===========================================================================
Audio     audio;  // 音频对象，负责流媒体和MP3播放
WiFiMulti wifiMulti;  // WiFi多连接管理
U8G2_SSD1306_128X64_NONAME_F_HW_I2C u8g2(U8G2_R0, U8X8_PIN_NONE, SCL, SDA);  // OLED显示对象
WebServer   server(80);  // Web服务器，用于WiFi配网
DNSServer   dnsServer;  // DNS服务器，用于配网模式
Preferences preferences;  // 非易失性存储，保存WiFi配置等

// 显示字符串
char infoString[MAX_INFO_LENGTH]   = "Audio Info:";  // 音频信息显示字符串
char stationString[MAX_INFO_LENGTH] = "station :";  // 电台名称显示字符串
char lastHost[MAX_INFO_LENGTH]     = "";  // 上次播放的URL
char errorInfoString[MAX_INFO_LENGTH] = "";  // 错误信息显示字符串

// 菜单状态
MenuState menuState         = MENU_NONE;  // 当前菜单状态
MenuState previousMenuState = MENU_NONE;  // 上一个菜单状态
int       menuIndex         = 0;  // 菜单当前选项索引
unsigned long menuStartTime = 0;  // 菜单进入时间，用于超时检测

// WiFi 配置
bool   configMode      = false;  // 是否处于WiFi配网模式
unsigned long configStartTime = 0;  // 配网开始时间
String newSSID = "", newPass = "";  // 新WiFi的SSID和密码
bool   wifiConfigExiting  = false;  // WiFi配置是否正在退出
bool   configPortalExiting = false;  // 配网门户是否正在退出

// 电台
String stationNames[MAX_STATIONS];  // 电台名称数组
String stationUrls[MAX_STATIONS];  // 电台URL数组

// 编码器
volatile int   encoderPos     = DEFAULT_VOLUME;  // 编码器位置（音量值）
volatile bool  encoderChanged = false;  // 编码器值是否改变
unsigned long  lastEncoderTime = 0;  // 上次编码器操作时间
bool           showingVolume  = false;  // 是否正在显示音量
unsigned long  volumeDisplayTime = 0;  // 音量显示开始时间
int            lastVolume     = -1;  // 上次音量值
volatile int8_t encoderDelta  = 0;  // 编码器增量值
volatile bool  buttonPressed  = false;  // 编码器按钮是否按下
volatile unsigned long lastButtonPress = 0;  // 上次按钮按下时间

// 开机动画状态
bool   bootScreenActive  = true;  // 开机动画是否激活显示
unsigned long bootScreenStartTime = 0;  // 开机动画开始时间
bool   audioSystemReady  = false;  // 音频系统是否就绪
bool   skipBootAnimation = false;  // 是否跳过开机动画

// SD 卡播放状态
bool   sdPlaying = false, sdPaused = false;  // SD卡播放状态和暂停状态
int    currentTrackIndex = 0, totalTracks = 0;  // 当前曲目索引和总曲目数
String* trackList;  // 曲目列表（动态分配，进入SD播放器时创建，退出时释放）
String currentTrackName = "";  // 当前曲目名称
unsigned long trackStartTime = 0, trackDuration = 0;  // 曲目开始时间和总时长
int    sdPlayerAnimType = 0;  // 播放器动画类型

// SD 卡扫描状态
bool  sdScanInProgress = false, sdScanComplete = false;  // 扫描是否进行中和是否完成
bool  sdScanTaskCreated = false, sdScanTaskShouldStop = false;  // 扫描任务是否创建和是否应该停止
unsigned long sdScanStartTime = 0;  // 扫描开始时间
int   sdScanProgress = 0, sdCheckedFiles = 0;  // 扫描进度和已检查文件数
int   sdEstimatedTotalFiles = 500, sdTotalMP3Files = 0;  // 预估总文件和实际MP3文件数
String sdScanStatus = "Initializing...";  // 扫描状态显示字符串

// SD 卡退出状态
bool  sdExitingInProgress = false;  // SD卡退出是否正在进行
unsigned long sdExitStartTime = 0;  // 退出开始时间
int   sdExitAnimationAngle = 0, clockGridAnimationPos = 0;  // 退出动画角度和时钟网格动画位置

// 并行扫描任务句柄
TaskHandle_t scanTaskHandles[MAX_SCAN_TASKS] = {NULL};  // 扫描任务句柄数组
volatile int activeScanTasks = 0;  // 当前活跃的扫描任务数
SemaphoreHandle_t scanResultMutex = NULL;  // 扫描结果互斥锁
String* scanFoundPaths;  // 扫描路径缓冲（动态分配，与trackList同生命周期）
volatile int scanFoundCount = 0;  // 扫描发现的文件数量

// 播放时间信息
unsigned long currentPlayTime = 0, totalPlayTime = 0;  // 当前播放时间和总播放时间
unsigned long lastPlayTimeUpdate = 0;  // 上次播放时间更新时刻
bool timeInfoAvailable = false;  // 时间信息是否可用
PlayMode currentPlayMode = PLAY_MODE_RANDOM;  // 当前播放模式（随机播放）
bool autoPlayEnabled = true;  // 是否启用自动播放

// 流媒体连接状态
bool  stationConnectingInProgress = false;  // 电台连接是否正在进行
unsigned long stationConnectStartTime = 0;  // 连接开始时间
int   stationConnectAnimationAngle = 0, stationConnectRetryCount = 0;  // 连接动画角度和重试次数
String connectingStationName = "", connectingStationUrl = "";  // 正在连接的电台名称和URL
bool  stationConnectFailed = false, forceStationConnectRetry = false;  // 连接是否失败和是否强制重试
bool  stationSwitching = false;  // 电台切换是否在进行
unsigned long stationSwitchStartTime = 0;  // 电台切换开始时间
int   lastSelectedStationIndex = -1;  // 上次选择的电台索引

// 音频系统状态
bool  audioSystemEnabled = true, audioLoopPaused = false;  // 音频系统是否启用和循环是否暂停
bool  audioSystemStopping = false;  // 音频系统是否正在停止
unsigned long audioStopStartTime = 0;  // 音频停止开始时间
bool  audioConnectionFailed = false;  // 音频连接是否失败
unsigned long lastConnectionAttempt = 0;  // 上次连接尝试时间
int   connectionRetryCount = 0;  // 连接重试次数
bool  wifiWasConnected = false;  // WiFi之前是否已连接
String savedSSID = "", savedPassword = "";  // 保存的WiFi名称和密码

// 音频质量监控状态
unsigned long lastAudioCheck = 0;  // 上次音频检查时间
unsigned long audioBufferUnderruns = 0, audioBufferOverruns = 0;  // 音频缓冲区欠载和过载次数
bool   audioQualityWarning = false;  // 音频质量警告标志
String audioQualityStatus = "Normal";  // 音频质量状态字符串

// 电池电量状态
uint8_t batteryLevelPercent = 100;  // 电池电量百分比
unsigned long lastBatteryCheck = 0;  // 上次电池检查时间

// OTA 升级配置
// OTA 服务器 URL — 定义为 String，由 loadOtaUrls() 从 NVS 读取
// 默认值写在 config.h（OTA_DEFAULT_VER_URL / OTA_DEFAULT_FW_URL）
String OTA_VERSION_URL  = "";  // 版本检查URL（setup()中由loadOtaUrls()填充）
String OTA_FIRMWARE_URL = "";  // 固件下载URL（setup()中由loadOtaUrls()填充）
String currentVersion  = "";  // 当前固件版本
float  currentVersionNum = 1.1f, serverVersionNum = 0.0f;  // 当前版本号和服务器版本号（数值）
String serverVersionStr = "";  // 服务器版本字符串
bool   otaUpdateAvailable = false, otaCheckCompleted = false;  // 是否有可用更新和检查是否完成
unsigned long otaCheckStartTime = 0;  // OTA检查开始时间
int    otaProgress = 0;  // OTA升级进度
bool   otaWiFiConnect = false;    // OTA是否需要WiFi连接
bool   naviWiFiConnect = false;   // Navidrome是否需要WiFi连接
bool   alarmWiFiConnect = false;  // 音乐闹钟是否需要WiFi连接
int    otaCheckResult = 0, otaAnimAngle = 0;  // OTA检查结果和动画角度

// CPU 监控状态
volatile uint32_t idleCount0 = 0, idleCount1 = 0;  // CPU空闲计数（两个核心）
float cpuUsage = 0.0f;  // CPU使用率
const uint32_t tickHz = configTICK_RATE_HZ;  // 系统时钟频率

// SD 卡互斥锁
SemaphoreHandle_t sdMutex = NULL;  // SD卡访问互斥量

// PONG 游戏状态
int ballX = 64, ballY = 32, ballDX = 2, ballDY = 1;  // 球的坐标和速度
int leftPaddleY = 24, rightPaddleY = 24;  // 左挡板和右挡板Y坐标
int leftScore = 0, rightScore = 0;  // 左分数和右分数
bool playerMode = false;  // 是否为玩家模式
int  gameTick   = 0;  // 游戏帧计数器

// 滚动显示状态
bool scrollStateResetFlag = false;  // 滚动状态重置标志

// Navidrome 播放器状态
String      naviServer           = "";     // Navidrome服务器地址
String      naviUser             = "";     // 用户名
String      naviPass             = "";     // 密码
bool        naviConfigValid      = false;  // 配置是否有效
int         naviSongCount        = 0;      // 歌曲总数
int         naviCurrentIdx       = 0;      // 当前播放索引
String      naviStatusMsg        = "";     // 状态提示文字
unsigned long naviTrackStartTime = 0;      // 当前曲目开始时间
int         naviCurrentDuration  = 0;      // 当前曲目时长（秒）
bool        naviPlaying          = false;  // 是否正在播放
unsigned long naviCurrentPlaySec = 0;      // 已播放秒数
NaviState   naviState            = NAVI_IDLE;  // 播放状态
NaviSong    naviSongList[ND_MAX_SONGS];   // 歌曲列表数组
bool        naviNeedsConfig      = false;   // Navidrome需要配置WEB服务
bool        startInNaviMode     = false;   // 重启后进入Navidrome模式
volatile bool naviStartRequested = false;  // 请求在主任务中执行 naviStart()（OLED Task 栈太小无法做HTTPS）
volatile bool naviReleasingMemory = false; // Navidrome正在用假连接触发 buffers freed，屏蔽 aggressiveMemoryCleanup
volatile bool naviPlayRetryRequested = false; // Navidrome播放失败，请求重试

// 音乐闹钟状态
int   alarmHour           = 7;     // 闹钟小时
int   alarmMinute         = 0;     // 闹钟分钟
bool  alarmEnabled        = false; // 闹钟是否启用
int   alarmSource         = 0;     // 音乐来源（0=MP3 1=IMP 2=Navidrome）
bool  alarmRepeat         = false; // 每天重复
bool  alarmRepeatActive   = false; // 重复模式激活：正在播放，等待用户操作返回闹钟
bool  alarmTriggered      = false; // 触发标志
int   alarmLastTriggerMin = -1;    // 上次触发分钟（防重复）
int   alarmEditHour       = 7;     // 编辑中的小时
int   alarmEditMin        = 0;     // 编辑中的分钟
int   alarmEditField      = 0;     // 当前编辑字段（0=小时 1=分钟 2=确认）

//===========================================================================
// 系统任务定义
//===========================================================================

// 空闲监控任务0（用于CPU使用率计算）
void idleMonitorTask0(void* arg) { while(1) { idleCount0++; vTaskDelay(1); } }
// 空闲监控任务1（用于CPU使用率计算）
void idleMonitorTask1(void* arg) { while(1) { idleCount1++; vTaskDelay(1); } }

// CPU监控任务（每秒计算一次CPU使用率）
void cpuMonitorTask(void* pvParameters) {
  uint32_t lastIdle0 = idleCount0, lastIdle1 = idleCount1;  // 上次的空闲计数
  while (1) {
    vTaskDelay(pdMS_TO_TICKS(1000));  // 每秒执行一次
    uint32_t nowIdle0 = idleCount0, nowIdle1 = idleCount1;  // 当前空闲计数
    uint32_t idleDiff  = (nowIdle0 - lastIdle0) + (nowIdle1 - lastIdle1);  // 计算空闲差值
    cpuUsage = constrain(100.0f * (1.0f - (float)idleDiff / (2 * tickHz)), 0.0f, 100.0f);  // 计算CPU使用率
    lastIdle0 = nowIdle0; lastIdle1 = nowIdle1;  // 更新上次计数
  }
}

// LED闪烁任务（蓝色LED，每秒切换一次状态）
void task1(void* pt) {
  pinMode(LED_BLUE, OUTPUT);  // 设置蓝色LED引脚为输出模式
  while (1) { digitalWrite(LED_BLUE, !digitalRead(LED_BLUE)); vTaskDelay(1000); }  // 每秒切换LED状态
}

//===========================================================================
// OLED 显示任务（菜单 + 动画 + SD 播放器界面）
// 注意：大量显示逻辑分布在此任务中，建议后续可拆到 oled_screens.h
//===========================================================================
void oledTask(void* pvParam);  // 声明，实现见下方

//===========================================================================
// FreeRTOS 栈溢出钩子 & 定期栈水位监控
// 需在 platformio.ini 中加入：
//   board_build.cmake_extra_args = -DCONFIG_FREERTOS_CHECK_STACKOVERFLOW=2
// 对应 idf.py menuconfig → FreeRTOS → Check for stack overflow → Method 2
//===========================================================================

// 栈溢出时由 FreeRTOS 内核调用（Method 2 可靠检测写越界）
extern "C" void vApplicationStackOverflowHook(TaskHandle_t xTask, char* pcTaskName) {
  Serial.print(F("[FATAL] Stack overflow in task: "));
  Serial.println(pcTaskName);
  Serial.printf("[FATAL] Remaining stack: %u words\n",
                (unsigned)uxTaskGetStackHighWaterMark(xTask));
  // 打印完后立即重启，避免系统进入未定义状态
  delay(200);
  ESP.restart();
}

// 定期打印所有任务的剩余栈水位（由 loop() 中的计时逻辑调用）
#if DEBUG_STACK_MONITOR
static void printTaskStackWatermarks() {
  static unsigned long _lastStackPrint = 0;
  if (millis() - _lastStackPrint < STACK_MONITOR_INTERVAL) return;
  _lastStackPrint = millis();

  Serial.println(F("=== Task Stack Watermarks (words) ==="));
  // 枚举所有任务（ESP-IDF 提供 uxTaskGetNumberOfTasks）
  UBaseType_t taskCount = uxTaskGetNumberOfTasks();
  TaskStatus_t* taskStatus =
      (TaskStatus_t*)pvPortMalloc(taskCount * sizeof(TaskStatus_t));
  if (taskStatus) {
    uint32_t totalRunTime = 0;
    UBaseType_t n = uxTaskGetSystemState(taskStatus, taskCount, &totalRunTime);
    for (UBaseType_t i = 0; i < n; i++) {
      Serial.printf("  %-20s  stack_min: %4u words  prio: %u\n",
                    taskStatus[i].pcTaskName,
                    (unsigned)taskStatus[i].usStackHighWaterMark,
                    (unsigned)taskStatus[i].uxCurrentPriority);
    }
    vPortFree(taskStatus);
  } else {
    Serial.println(F("  [WARN] pvPortMalloc failed for task list"));
  }
  Serial.printf("  Free heap: %u KB\n", ESP.getFreeHeap() / 1024);
  Serial.println(F("====================================="));
}
#endif  // DEBUG_STACK_MONITOR
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
void loop() {

  static unsigned long _loopCount = 0;
static unsigned long _lastLoopLog = 0;
if (millis() - _lastLoopLog > 30000) {
    _lastLoopLog = millis();
    Serial.printf("[LOOP] alive cnt=%lu heap=%u menuState=%d naviState=%d\n",
                  _loopCount, ESP.getFreeHeap(), menuState, naviState);
}
_loopCount++;

  // 串口命令处理
  if (Serial.available()) {  // 检查串口是否有数据
    String cmd = Serial.readStringUntil('\n');  // 读取一行命令
    cmd.trim();  // 去除首尾空格
    if (cmd == "refresh" || cmd == "refreshsd") {  // 刷新SD卡数据库命令
      Serial.println("Refreshing SD card database...");  // 打印提示信息
      deleteTrackDatabase();  // 删除曲目数据库
      totalTracks = 0; sdScanComplete = false; sdScanInProgress = true;  // 重置扫描状态
      sdScanStatus = "Refreshing...";  // 更新扫描状态
    } else if (cmd == "dbinfo") {  // 数据库信息命令
      Serial.print("Total tracks: ");   Serial.println(totalTracks);  // 打印总曲目数
      Serial.print("DB file exists: "); Serial.println(SD.exists(DB_FILE) ? "Yes" : "No");  // 打印数据库文件是否存在
      Serial.print("Free heap: ");      Serial.println(ESP.getFreeHeap());  // 打印空闲内存
    } else if (cmd == "help") {  // 帮助命令
      Serial.println("refresh / dbinfo / help");  // 打印可用命令
    }
  }

  // 音频主循环（处理音频解码和播放）
  if (!audioLoopPaused) audio.loop();  // 如果未暂停则执行音频循环

  unsigned long currentTime = millis();  // 获取当前运行时间
  esp_task_wdt_reset();  // 重置看门狗定时器

  asyncAudioSystemCleanup();  // 异步清理音频系统
  processStationConnection();  // 处理电台连接
  processStationSwitching();  // 处理电台切换（新增）
  pollWiFiConnection();  // 轮询WiFi连接状态（非阻塞启动后在此检测结果）

  // 电池电量检测（按固定间隔检测）
  if (currentTime - lastBatteryCheck >= BATTERY_CHECK_INTERVAL) {  // 达到检测间隔
    checkBatteryLevel(); lastBatteryCheck = currentTime;  // 检测电池电量并更新时间
  }

  // 非音频操作节流（50ms）
  static unsigned long lastNonAudioTime = 0;  // 上次非音频操作时间
  if (currentTime - lastNonAudioTime < 50) return;  // 如果小于50ms则返回
  lastNonAudioTime = currentTime;  // 更新上次时间

  // 串口 URL 输入（直接播放网络流）
  if (Serial.available()) {  // 检查串口是否有数据
    audio.stopSong();  // 停止当前播放
    if (ESP.getMaxAllocHeap() < 16384) aggressiveMemoryCleanup();  // 内存不足时清理
    digitalWrite(I2S_SD_MODE, 1);  // 使能I2S功放
    esp_task_wdt_reset();  // 重置看门狗
    String r = Serial.readString(); r.trim();  // 读取URL字符串
    if (r.length() > 5) { audio.connecttohost(r.c_str()); resetConfigMode(); }  // 连接播放网络流
  }

  // ── 每天重复模式拦截 ──────────────────────────────────────────────────
  // 闹钟触发后处于重复模式时，任何按钮按下或旋转编码器操作都会：
  //   1. 停止当前播放
  //   2. 回到音乐闹钟界面等待下次触发
  // 用户如需切换播放器，需从闹钟子菜单选择"返回选择界面"
  if (alarmRepeatActive && (buttonPressed || encoderChanged)) {
    Serial.println("[Alarm] Repeat mode: user input detected, returning to alarm clock");
    buttonPressed  = false;
    encoderChanged = false;
    encoderDelta   = 0;

    // 停止当前播放（根据当前状态做对应清理）
    if (sdPlaying || menuState == MENU_SD_PLAYER || menuState == MENU_SD_LOADING) {
      // MP3播放器：停止SD播放，释放内存，重连WiFi
      audio.stopSong(); sdPlaying = false; sdPaused = false;
      sdScanTaskShouldStop = true; sdScanInProgress = false;
      for (int i = 0; i < MAX_TRACKS; i++) { if (trackList)      { trackList[i]      = ""; trackList[i].reserve(0); } }
      for (int i = 0; i < MAX_TRACKS; i++) { if (scanFoundPaths) { scanFoundPaths[i]  = ""; scanFoundPaths[i].reserve(0); } }
      freeSDBuffers();
      totalTracks = 0; sdTotalMP3Files = 0; scanFoundCount = 0;
      safeStopAudioSystem(); delay(300);
      aggressiveMemoryCleanup();
      // 重连WiFi（闹钟时钟界面需要WiFi保持NTP同步）
      if (WiFi.status() != WL_CONNECTED) {
        alarmWiFiConnect = true;
        menuState  = MENU_WIFI_CONNECTING;
        menuIndex  = 0;
        menuStartTime = millis();
        stationConnectAnimationAngle = random(0, 12) * 30;
        strcpy(stationString, "正在连接WiFi...");
        strcpy(infoString, "请稍候");
      } else {
        menuState = MENU_ALARM_CLOCK;
        menuIndex = 0;
        menuStartTime = millis();
        digitalWrite(I2S_SD_MODE, 0);  // 关闭功放省电
      }
    } else if (naviPlaying || menuState == MENU_NAVI_PLAYER) {
      // Navidrome：停止播放
      audio.stopSong();
      naviPlaying = false;
      naviState   = NAVI_IDLE;
      menuState = MENU_ALARM_CLOCK;
      menuIndex = 0;
      menuStartTime = millis();
      digitalWrite(I2S_SD_MODE, 0);  // 关闭功放省电
    } else {
      // IMP网络播放器或其他状态
      audio.stopSong();
      menuState = MENU_ALARM_CLOCK;
      menuIndex = 0;
      menuStartTime = millis();
      digitalWrite(I2S_SD_MODE, 0);  // 关闭功放省电
    }

    alarmRepeatActive = false;  // 清除拦截标志，等待下次触发重新设置
  }

  // 编码器旋转处理
  if (encoderChanged) {  // 检测到编码器变化
    encoderChanged = false;  // 清除变化标志
    if (menuState != MENU_NONE) {  // 如果在菜单中
      handleMenuRotation();  // 处理菜单旋转
    } else {  // 如果不在菜单中
      encoderPos = constrain(encoderPos, 0, 21);  // 限制音量范围
      audio.setVolume(encoderPos);  // 设置音量
      showingVolume = true; volumeDisplayTime = millis();  // 显示音量
    }
  }

  // 音量显示超时处理
  if (showingVolume && (millis() - volumeDisplayTime > 2000)) showingVolume = false;  // 2秒后隐藏音量显示
  if (menuState == MENU_ANIMATION && showingVolume) showingVolume = false;  // 动画模式下隐藏音量

  // 菜单超时处理
  if ((menuState == MENU_MAIN || menuState == MENU_STATION_SELECT) &&  // 主菜单或电台选择菜单
      (millis() - menuStartTime > MENU_TIMEOUT)) {  // 超过菜单超时时间
    if (menuState == MENU_STATION_SELECT) safeRestartAudioSystem();  // 电台选择菜单需要重启音频系统
    resetScrollState();
    // 如果Navidrome处于活动状态，超时后返回Navidrome界面而非主屏幕
    if (naviState == NAVI_PLAYING || naviState == NAVI_PAUSED ||
        naviState == NAVI_CONNECTING || naviState == NAVI_LOADING ||
        naviState == NAVI_ERROR) {
      menuState = MENU_NAVI_PLAYER;  // 返回Navidrome播放器界面
      menuStartTime = millis();
    } else {
      menuState = MENU_NONE;  // 退出菜单
    }
  }

  // Navidrome控制菜单超时处理（15秒返回播放器界面，菜单项增加到8项适当延长）
  if (menuState == MENU_NAVI_CONTROL && millis() - menuStartTime > 15000) {
    encoderPos = constrain(encoderPos, 0, 21);
    menuState = MENU_NAVI_PLAYER;
    menuStartTime = millis();
  }

  // 闹钟子菜单/时间设置/来源设置超时（30秒无操作返回时钟界面）
  if ((menuState == MENU_ALARM_SUBMENU ||
       menuState == MENU_ALARM_SET_TIME ||
       menuState == MENU_ALARM_SET_SOURCE) &&
      millis() - menuStartTime > 30000) {
    menuState = MENU_ALARM_CLOCK;
    menuIndex = 0;
    menuStartTime = millis();
  }

  // SD控制菜单超时处理
  if (menuState == MENU_SD_CONTROL && millis() - menuStartTime > 10000) {  // SD控制菜单超时10秒
    encoderPos = constrain(encoderPos, 0, 21); menuState = MENU_SD_PLAYER;  // 返回播放器界面
  }

  // SD动画选择菜单超时处理
  if (menuState == MENU_SD_ANIMATION_SELECT && millis() - menuStartTime > 10000) {  // 动画选择超时10秒
    encoderPos = constrain(encoderPos, 0, 21); menuState = MENU_SD_PLAYER;  // 返回播放器界面
  }

  // 播放器选择菜单超时处理：启动WiFi连接，连接成功后进入IMP播放器
  if (menuState == MENU_PLAYER_SELECT && millis() - menuStartTime > 30000) {  // 选择器超时30秒
    encoderPos = DEFAULT_VOLUME; audio.setVolume(encoderPos); digitalWrite(I2S_SD_MODE, 1);  // 恢复默认音量
    bool wifiStarted = startConnectToWiFi();  // 启动WiFi连接（非阻塞）
    if (wifiStarted) {
      menuState     = MENU_WIFI_CONNECTING;  // 进入WiFi连接等待界面
      menuStartTime = millis();               // 记录开始时间
      strcpy(stationString, "正在连接WiFi");
      strcpy(infoString,    "请稍候...");
    }
  }

  // SD 卡退出状态机
  // 重启是清除 SD 播放造成的堆碎片的唯一可靠方法。
  // 最小化重启前的操作，让 OLED 的滚动方块动画播放一到两帧后立即重启，
  // 避免用户看到空白或卡顿的网络播放器界面。
  // 重启后 setup() 检测到 restartFromSD=true，在干净的堆上连接 WiFi，
  // 进入网络播放器时声音几乎立即出现。
  if (menuState == MENU_SD_EXITING && sdExitingInProgress) {
    if (wifiConfigExiting) {
      // WiFi 配置退出：不重启，直接切换到配置门户
      audio.stopSong(); audioLoopPaused = true; delay(100);
      WiFi.disconnect(true); WiFi.mode(WIFI_OFF); delay(100);
      aggressiveMemoryCleanup();
      wifiConfigExiting    = false;
      sdExitingInProgress  = false;
      startConfigPortal();
      menuState = MENU_NONE;
      return;
    } else if (configPortalExiting) {
      // 配置门户退出：不重启，直接切换
      WiFi.softAPdisconnect(true); WiFi.mode(WIFI_OFF); delay(100);
      aggressiveMemoryCleanup();
      sdExitingInProgress  = false;
      configPortalExiting  = false;
      menuState = MENU_WIFI_CONNECTING;
      menuIndex = 0;
      menuStartTime = millis();
      stationConnectAnimationAngle = random(0, 12) * 30;
      strcpy(stationString, "正在扫描WiFi...");
      strcpy(infoString,    "请稍候");
    } else {
      // 正常 SD 退出：停止音频，立即重启
      // OLED 任务此时正在显示滚动方块动画，重启在动画播放约1-2帧后触发
      audio.stopSong();
      sdScanTaskShouldStop = true;
      sdPlaying = false; sdPaused = false;
      delay(300);  // 让 OLED 至少渲染一帧动画，用户能看到过渡效果
      Serial.println("[SD Exit] Restarting for clean heap...");
      preferences.putBool("restartFromSD", true);
      ESP.restart();
    }
  }
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

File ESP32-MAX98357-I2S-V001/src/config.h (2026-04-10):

#ifndef CONFIG_H  // 防止头文件重复包含
#define CONFIG_H  // 定义配置头文件宏

//========================== 调试开关 ==========================  // 调试功能配置区域
#define DEBUG_MODE false  // 通用调试模式开关（true开启，false关闭）
#define DEBUG_STREAM_INFO false  // 流媒体信息调试开关
#define DEBUG_NAVI_VERBOSE false  // Navidrome详细日志开关
#define DEBUG_MP3_INFO true  // MP3播放信息调试开关

//========================== FreeRTOS 栈溢出检测 ==========================
// 说明：需在 platformio.ini（或 sdkconfig）中同时启用：
//   board_build.cmake_extra_args =
//     -DCONFIG_FREERTOS_CHECK_STACKOVERFLOW=2
// 或通过 idf.py menuconfig → FreeRTOS → Check for stack overflow → Method 2
//
// 启用后，当任何任务栈溢出时 vApplicationStackOverflowHook() 被调用，
// 串口打印任务名 + 剩余栈深度，随后触发 ESP.restart() 保护系统。
//
// DEBUG_STACK_MONITOR true  → 每隔 STACK_MONITOR_INTERVAL ms 打印各任务剩余栈水位
// DEBUG_STACK_MONITOR false → 仅在溢出时打印（生产环境推荐值）
#define DEBUG_STACK_MONITOR     false        // 定期打印任务栈水位（开发阶段设为true）
#define STACK_MONITOR_INTERVAL  30000UL      // 栈水位打印间隔（毫秒）
#define OLED_TASK_STACK_SIZE    (1024 * 6)   // OLED Task栈大小（字节），与xTaskCreate保持一致

//========================== 引脚定义 ==========================  // 硬件引脚配置区域

// SD卡硬件引脚定义  // SD卡SPI接口引脚配置
#define SD_CS          5  // SD卡片选引脚（CS）
#define SPI_MOSI      23  // SPI主机输出从机输入引脚
#define SPI_MISO      19  // SPI主机输入从机输出引脚
#define SPI_SCK       18  // SPI时钟引脚

// OLED显示屏引脚  // OLED显示模块I2C接口引脚
#define SCL 14  // I2C时钟引脚
#define SDA 4  // I2C数据引脚

// I2S音频引脚  // I2S音频接口配置
#define I2S_DOUT      25  // I2S数据输出引脚
#define I2S_BCLK      27  // I2S位时钟引脚
#define I2S_LRC       26  // I2S左右声道时钟引脚
#define I2S_SD_MODE   21  // I2S功放使能引脚
#define LED_BLUE      33  // 蓝色LED指示灯引脚

// 旋转编码器引脚  // 旋转编码器接口配置
#define ENCODER_CLK    32  // 编码器时钟引脚（CLK）
#define ENCODER_DT     16  // 编码器数据引脚（DT）
#define ENCODER_SW     17  // 编码器按钮引脚（SW）

// 液晶背光引脚  // LCD背光控制引脚（预留）
#define LED_LAN_1     14  // 背光控制引脚1
#define LED_LAN_2     28  // 背光控制引脚2
#define LED_LAN_3     44  // 背光控制引脚3

// 电池电量检测引脚  // 电池ADC检测引脚
#define BAT_DAC      36  // 电池电量ADC输入引脚

//========================== WiFi配置 ==========================  // WiFi网络配置区域
#define AP_SSID "ESP32_Radio"  // 设备作为AP热点时的SSID名称
#define AP_PASS ""  // AP热点密码（空字符串表示无密码）
#define CONFIG_PORTAL_TIMEOUT 180  // 配置门户超时时间（秒）

//========================== 电台配置 ==========================  // 网络电台配置区域
#define MAX_STATIONS 20  // 最大保存电台数量

//========================== 菜单配置 ==========================  // 菜单系统配置区域
#define MENU_TIMEOUT 10000  // 菜单自动退出超时时间（毫秒）
#define MAIN_MENU_COUNT 8  // 主菜单选项数量（含Navidrome）

//========================== SD扫描配置 ==========================  // SD卡扫描配置区域
#define MAX_SCAN_TASKS 2  // 最大并行扫描任务数（减少SD卡竞争）
#define MAX_TRACKS 500  // 最大曲目数量
#define SD_SCAN_TIMEOUT_ENABLED false  // SD扫描超时检测是否启用
#define SCAN_TIMEOUT 300000  // SD扫描超时时间（毫秒）

//========================== 时间配置 ==========================  // 超时时间配置区域
#define STATION_SWITCH_TIMEOUT 10000  // 电台切换超时时间（毫秒）
#define CONNECTION_TIMEOUT 15000  // 连接超时时间（毫秒）
#define STATION_CONNECT_TIMEOUT 20000  // 电台连接超时时间（毫秒）
#define SD_EXIT_TIMEOUT 8000  // SD卡模式退出超时时间（毫秒）
#define BATTERY_CHECK_INTERVAL 10000  // 电池电量检测间隔（毫秒）
#define AUDIO_STOP_TIMEOUT 3000  // 音频停止超时时间（毫秒）

//========================== 显示配置 ==========================  // 显示相关配置区域
#define MAX_INFO_LENGTH 128  // 信息字符串最大长度

//========================== OTA配置 ==========================  // OTA升级配置区域
#define OTA_VERSION_KEY      "fw_ver"                                              // NVS中存储固件版本的键名
#define DEFAULT_VERSION      "1.1.05"                                              // 默认固件版本号
#define DB_FILE              "/tracks.db"                                          // SD卡曲目数据库文件名

//========================== OTA URL 配置（NVS 可覆盖） ==========================
// 两个 URL 优先从 NVS 读取（键名如下），若 NVS 中为空则回落到以下编译期默认值。
// 用户可通过 Web 界面 /ota/config 修改并保存到 NVS，无需重新编译固件。
#define OTA_NVS_KEY_VER_URL  "ota_ver_url"                                        // NVS键：版本检查URL
#define OTA_NVS_KEY_FW_URL   "ota_fw_url"                                         // NVS键：固件下载URL
#define OTA_DEFAULT_VER_URL  "http://YOUR_SERVER_IP"  // 默认版本检查URL
#define OTA_DEFAULT_FW_URL   "http://YOUR_SERVER_IP"  // 默认固件下载URL

//========================== 全局变量声明 ==========================  // 全局变量声明区域

#endif // CONFIG_H  // 结束头文件保护

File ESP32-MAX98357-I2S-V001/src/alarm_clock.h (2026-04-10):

#ifndef ALARM_CLOCK_H
#define ALARM_CLOCK_H

// ============================================================
// 音乐闹钟模块（含诊断日志版）
// ============================================================

#include "globals.h"
#include "config.h"

// ---- NVS 键名 ----
#define ALARM_NVS_HOUR    "alm_hour"
#define ALARM_NVS_MIN     "alm_min"
#define ALARM_NVS_ENABLED "alm_en"
#define ALARM_NVS_SOURCE  "alm_src"
#define ALARM_NVS_REPEAT  "alm_rep"

// ============================================================
// ★ 诊断开关 — 上线调试期间设为 true，确认稳定后改回 false
// ============================================================
#define ALARM_DEBUG true

// 诊断日志宏（只在 ALARM_DEBUG=true 时编译）
#if ALARM_DEBUG
  #define ALARM_LOG(fmt, ...)  Serial.printf("[ALARM-DBG] " fmt "\n", ##__VA_ARGS__)
#else
  #define ALARM_LOG(fmt, ...)
#endif

// 定期内存清理间隔（3分钟）
#define ALARM_MEMORY_CLEANUP_INTERVAL_MS 180000UL  // 3 * 60 * 1000
static unsigned long lastAlarmMemoryCleanup = 0;

// ============================================================
// 诊断：定期心跳（每 60 秒打印一次系统健康信息）
// 在 loop() 内调用 alarmHeartbeat()，或由 checkAlarmTrigger() 内嵌调用
// ============================================================
void alarmHeartbeat() {
#if ALARM_DEBUG
  static unsigned long _lastHeartbeat = 0;
  unsigned long now = millis();
  if (now - _lastHeartbeat < 60000UL) return;
  _lastHeartbeat = now;

  // ---- 基础内存 ----
  uint32_t freeHeap    = ESP.getFreeHeap();
  uint32_t maxAlloc    = ESP.getMaxAllocHeap();
  uint32_t minFreeHeap = ESP.getMinFreeHeap();

  // ---- WiFi 状态 ----
  bool wifiConn  = (WiFi.status() == WL_CONNECTED);
  int  rssi      = wifiConn ? WiFi.RSSI() : 0;

  // ---- NTP 时间 ----
  struct tm ti;
  bool gotTime = getLocalTime(&ti, 0);

  // ---- 音频系统 ----
  int  bufFilled = audio.inBufferFilled();
  int  bufFree   = audio.inBufferFree();

  Serial.println(F("====== [ALARM HEARTBEAT] ======"));
  Serial.printf("  Uptime     : %lu s\n",       now / 1000);
  Serial.printf("  Free heap  : %u KB\n",       freeHeap / 1024);
  Serial.printf("  MinFree    : %u KB\n",       minFreeHeap / 1024);
  Serial.printf("  MaxAlloc   : %u KB\n",       maxAlloc / 1024);
  Serial.printf("  WiFi       : %s  RSSI=%d dBm\n", wifiConn ? "OK" : "DOWN", rssi);
  Serial.printf("  NTP time   : %s  %s\n",
                gotTime ? "OK" : "FAIL",
                gotTime ? asctime(&ti) : "---");
  Serial.printf("  audioLoop  : paused=%d  bufFilled=%d  bufFree=%d\n",
                (int)audioLoopPaused, bufFilled, bufFree);
  Serial.printf("  menuState  : %d\n", (int)menuState);
  Serial.printf("  alarmEn    : %d  %02d:%02d  src=%d  repeat=%d\n",
                (int)alarmEnabled, alarmHour, alarmMinute,
                alarmSource, (int)alarmRepeat);
  Serial.printf("  lastTrigMin: %d\n", alarmLastTriggerMin);

  // ---- FreeRTOS 任务栈水位（诊断关键：判断栈是否即将溢出）----
  // uxTaskGetStackHighWaterMark(NULL) = 当前任务（loop/main task）
  Serial.printf("  Stack(loop): %u words remaining\n",
                (unsigned)uxTaskGetStackHighWaterMark(NULL));

  Serial.println(F("============================================================"));
#endif
}

// ---- 从 NVS 加载闹钟配置 ----
void loadAlarmConfig() {
    alarmHour    = preferences.getInt(ALARM_NVS_HOUR,    7);
    alarmMinute  = preferences.getInt(ALARM_NVS_MIN,     0);
    alarmEnabled = preferences.getBool(ALARM_NVS_ENABLED, false);
    alarmSource  = preferences.getInt(ALARM_NVS_SOURCE,  0);
    alarmRepeat  = preferences.getBool(ALARM_NVS_REPEAT, false);
    Serial.printf("[Alarm] Loaded: %02d:%02d enabled=%d src=%d repeat=%d\n",
                  alarmHour, alarmMinute, alarmEnabled, alarmSource, alarmRepeat);
}

// ---- 将闹钟配置保存到 NVS ----
void saveAlarmConfig() {
    preferences.putInt(ALARM_NVS_HOUR,    alarmHour);
    preferences.putInt(ALARM_NVS_MIN,     alarmMinute);
    preferences.putBool(ALARM_NVS_ENABLED, alarmEnabled);
    preferences.putInt(ALARM_NVS_SOURCE,  alarmSource);
    preferences.putBool(ALARM_NVS_REPEAT, alarmRepeat);
    Serial.printf("[Alarm] Saved: %02d:%02d enabled=%d src=%d repeat=%d\n",
                  alarmHour, alarmMinute, alarmEnabled, alarmSource, alarmRepeat);
}

// ---- 音乐来源名称（用于显示） ----
const char* alarmSourceName(int src) {
    switch (src) {
        case 0: return "MP3播放器";
        case 1: return "IMP播放器";
        case 2: return "Navidrome";
        default: return "MP3播放器";
    }
}

// ---- 触发闹钟：根据 alarmSource 启动对应播放器 ----
void triggerAlarm() {
    Serial.printf("[Alarm] TRIGGERED! source=%d repeat=%d\n", alarmSource, alarmRepeat);
    ALARM_LOG("triggerAlarm(): freeHeap=%u KB  maxAlloc=%u KB  WiFi=%s",
              ESP.getFreeHeap() / 1024, ESP.getMaxAllocHeap() / 1024,
              (WiFi.status() == WL_CONNECTED) ? "OK" : "DOWN");

    // 触发前统一清理内存
    Serial.println("[Alarm] Pre-alarm memory cleanup...");
    aggressiveMemoryCleanup();

    alarmTriggered = false;

    if (alarmRepeat) {
        alarmRepeatActive = true;
        alarmLastTriggerMin = alarmMinute;
        Serial.println("[Alarm] Repeat mode: will return to alarm clock on user input");
    } else {
        alarmEnabled = false;
        alarmRepeatActive = false;
        saveAlarmConfig();
    }

    if (alarmSource == 0) {
        // ── MP3 播放器 ──────────────────────────────────────────
        audio.stopSong();
        audioLoopPaused = true;
        delay(200);
        disconnectWiFiForSDPlayback();
        delay(200);
        encoderPos = DEFAULT_VOLUME;
        audio.setVolume(encoderPos);

        if (!sdScanTaskCreated) {
            if (xTaskCreatePinnedToCore(sdScanTask, "SD Scan Task", 8192, NULL, 1, NULL, 1) == pdPASS)
                sdScanTaskCreated = true;
        }
        if ((!sdScanComplete && !sdScanInProgress) || (sdScanComplete && totalTracks == 0)) {
            sdScanInProgress = true;
            sdScanComplete   = false;
            sdScanStartTime  = millis();
            sdScanProgress   = 0;
            sdScanStatus     = "Starting scan...";
            menuState        = MENU_SD_LOADING;
        } else if (sdScanComplete && totalTracks > 0) {
            safeRestartAudioSystem();
            delay(100);
            int idx = (millis() % totalTracks);
            if (idx == 0) idx = 1;
            playTrack(idx);
            digitalWrite(I2S_SD_MODE, 1);
            menuState  = MENU_SD_PLAYER;
            loadSDAnimationType();
            sdPlaying  = true;
            sdPaused   = false;
        } else {
            menuState = MENU_SD_LOADING;
        }
        menuIndex     = 0;
        menuStartTime = millis();
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
